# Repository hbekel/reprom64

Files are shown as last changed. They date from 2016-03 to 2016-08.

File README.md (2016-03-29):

#reprom64
*rom replacement board for the C64*

This is a rom adapter board for the C64 which replaces all rom chips
with a single 64kb 27C512 Eprom, offering space for four different
kernals, four charsets and two basic roms.

It can be assembled for any C64 mainboard as well as for the SX64 CPU
board.

Please refer to the [project
page](http://www.henning-bekel.de/reprom64) for detailed
documentation.

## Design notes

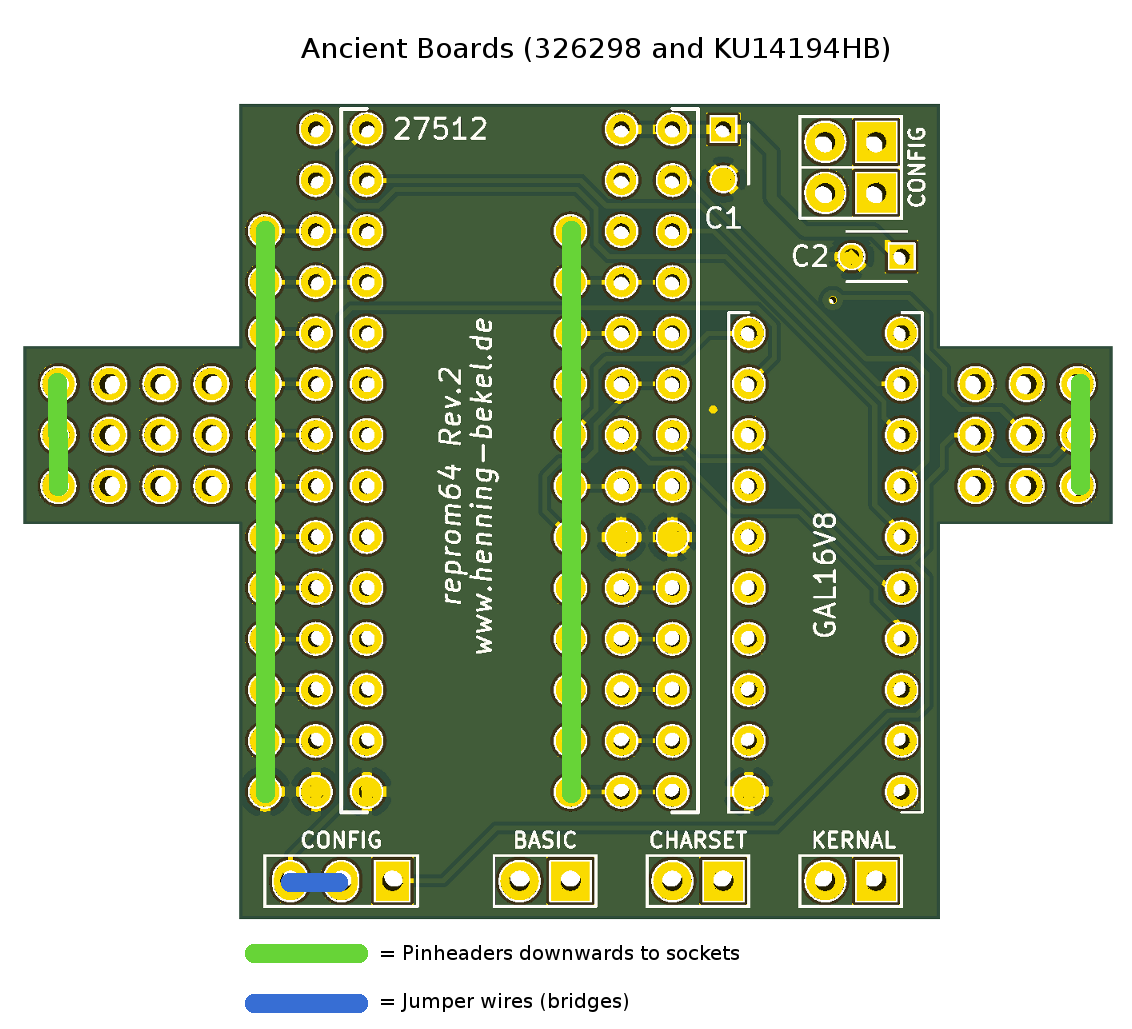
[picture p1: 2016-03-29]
doc/reprom-ancient-board.png

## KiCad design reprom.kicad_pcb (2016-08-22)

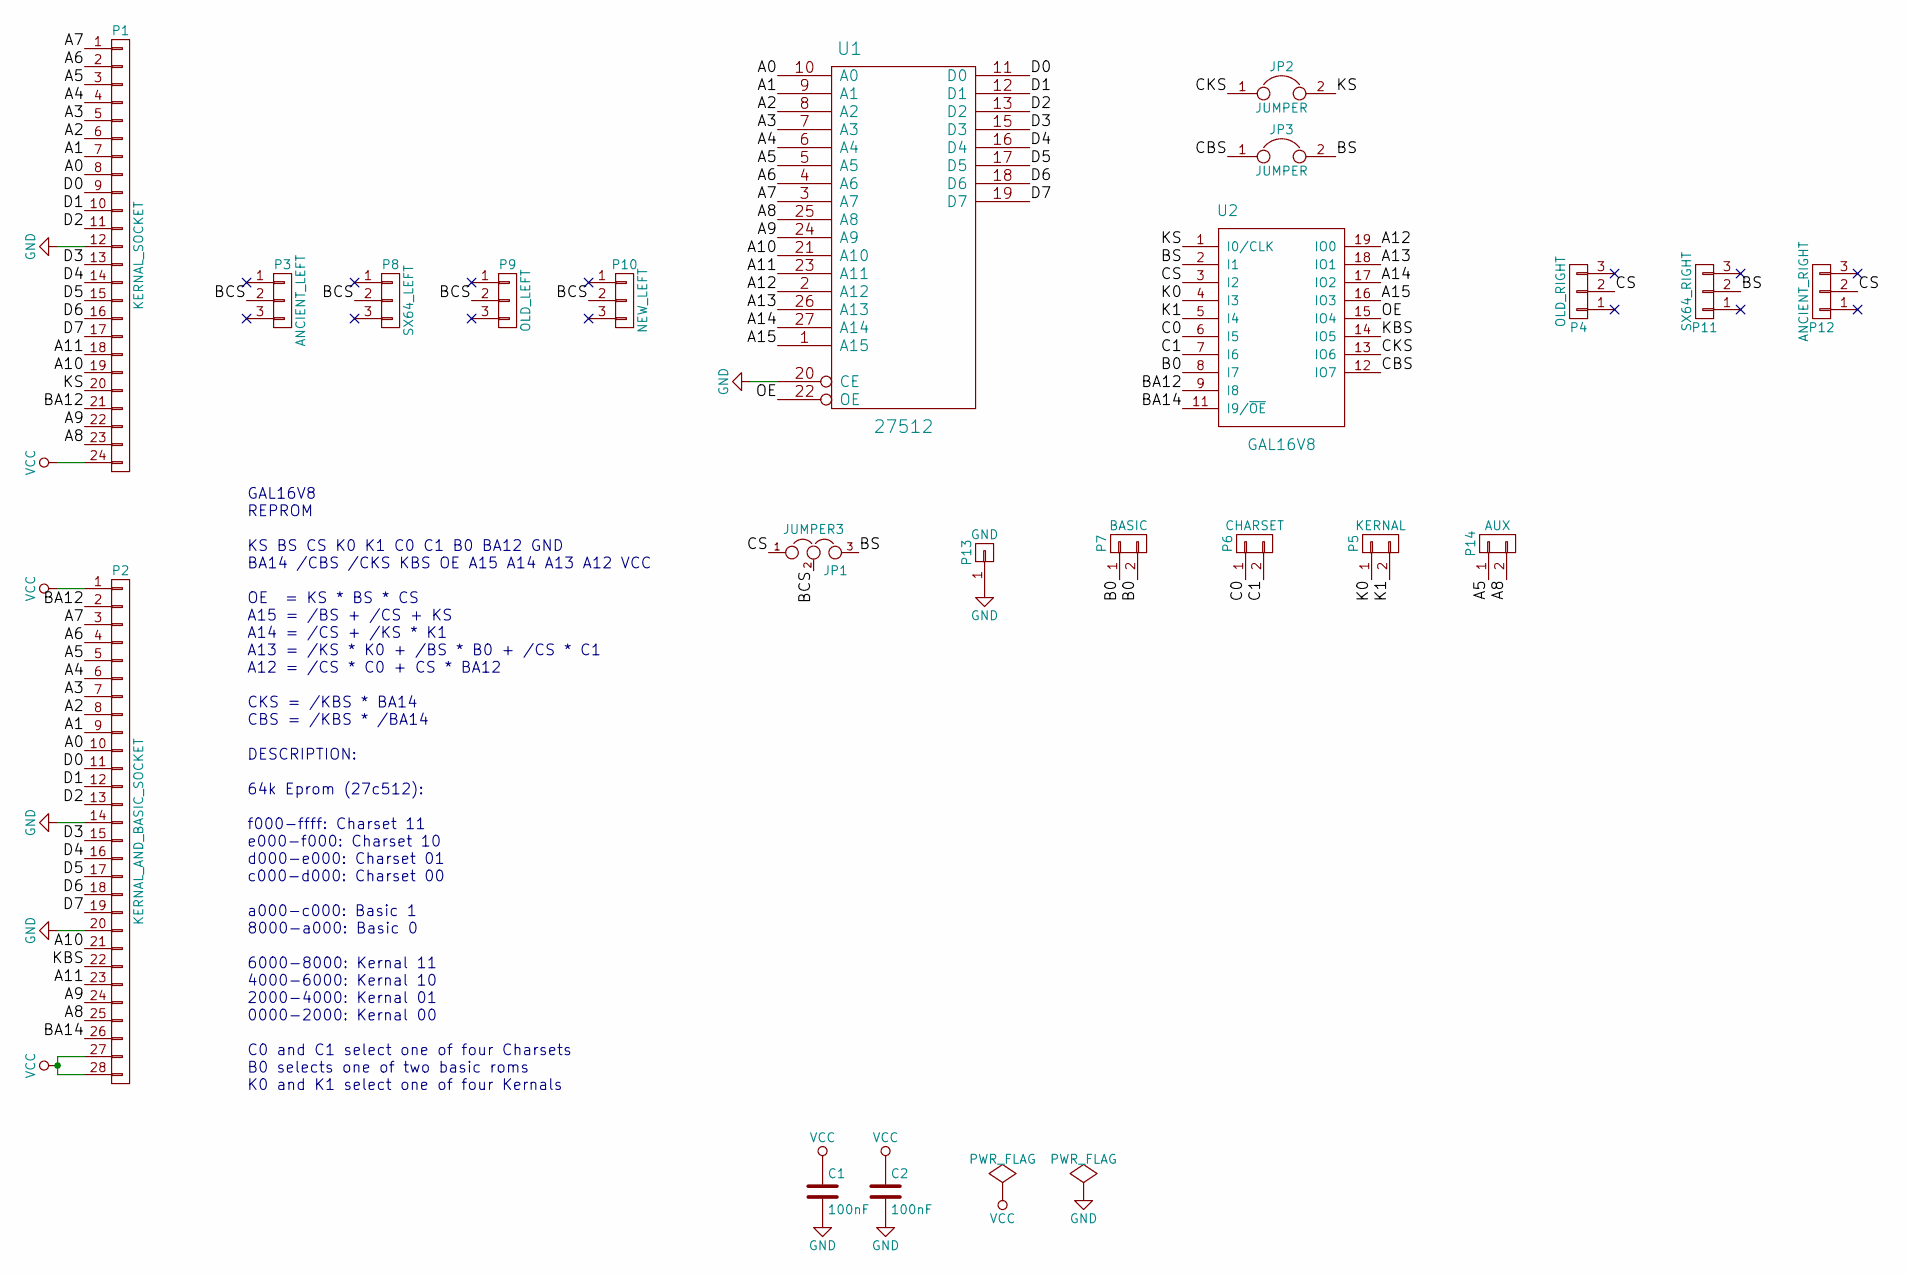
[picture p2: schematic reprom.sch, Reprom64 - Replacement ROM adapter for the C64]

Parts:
C1, C2: 100nF; C_Disc_D3_P2.5
JP1: JUMPER3; Pin_Header_Straight_1x03
JP2, JP3: JUMPER; Pin_Header_Straight_1x02
P1: KERNAL_SOCKET; DIP-24_W15.24mm
P2: KERNAL_AND_BASIC_SOCKET; DIP-28_W15.24mm
P3: ANCIENT_LEFT; Pin_Header_Straight_1x03
P4: OLD_RIGHT; Pin_Header_Straight_1x03
P5: KERNAL; Pin_Header_Straight_1x02
P6: CHARSET; Pin_Header_Straight_1x02
P7: BASIC; Pin_Header_Straight_1x02
P8: SX64_LEFT; Pin_Header_Straight_1x03
P9: OLD_LEFT; Pin_Header_Straight_1x03
P10: NEW_LEFT; Pin_Header_Straight_1x03
P11: SX64_RIGHT; Pin_Header_Straight_1x03
P12: ANCIENT_RIGHT; Pin_Header_Straight_1x03
P13: GND; Pin_Header_Straight_1x01
P14: AUX; Pin_Header_Straight_1x02
U1: 27512; DIP-28_W15.24mm
U2: GAL16V8; DIP-20_W7.62mm

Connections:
/A0: P1.8, P2.10, U1.10 (A0)
/A1: P1.7, P2.9, U1.9 (A1)
/A2: P1.6, P2.8, U1.8 (A2)
/A3: P1.5, P2.7, U1.7 (A3)
/A4: P1.4, P2.6, U1.6 (A4)
/A5: P1.3, P2.5, P14.1, U1.5 (A5)
/A6: P1.2, P2.4, U1.4 (A6)
/A7: P1.1, P2.3, U1.3 (A7)
/A8: P1.23, P2.25, P14.2, U1.25 (A8)
/A9: P1.22, P2.24, U1.24 (A9)
/A10: P1.19, P2.21, U1.21 (A10)
/A11: P1.18, P2.23, U1.23 (A11)
/A12: U1.2 (A12), U2.19 (IO0)
/A13: U1.26 (A13), U2.18 (IO1)
/A14: U1.27 (A14), U2.17 (IO2)
/A15: U1.1 (A15), U2.16 (IO3)
/B0: P7.1, P7.2, U2.8 (I7)
/BA12: P1.21, P2.2, U2.9 (I8)
/BA14: P2.26, U2.11 (I9/~OE)
/BCS: JP1.2, P3.2, P8.2, P9.2, P10.2
/BS: JP1.3, JP3.2, P11.2, U2.2 (I1)
/C0: P6.1, U2.6 (I5)
/C1: P6.2, U2.7 (I6)
/CBS: JP3.1, U2.12 (IO7)
/CKS: JP2.1, U2.13 (IO6)
/CS: JP1.1, P4.2, P12.2, U2.3 (I2)
/D0: P1.9, P2.11, U1.11 (D0)
/D1: P1.10, P2.12, U1.12 (D1)
/D2: P1.11, P2.13, U1.13 (D2)
/D3: P1.13, P2.15, U1.15 (D3)
/D4: P1.14, P2.16, U1.16 (D4)
/D5: P1.15, P2.17, U1.17 (D5)
/D6: P1.16, P2.18, U1.18 (D6)
/D7: P1.17, P2.19, U1.19 (D7)
/K0: P5.1, U2.4 (I3)
/K1: P5.2, U2.5 (I4)
/KBS: P2.22, U2.14 (IO5)
/KS: JP2.2, P1.20, U2.1 (I0/CLK)
/OE: U1.22 (OE), U2.15 (IO4)
GND: C1.2, C2.2, P1.12, P2.14, P2.20, P13.1, U1.14 (GND), U1.20 (CE), U2.10 (GND)
VCC: C1.1, C2.1, P1.24, P2.1, P2.27, P2.28, U1.28 (VCC), U2.20 (VCC)

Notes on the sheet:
GAL16V8 REPROM KS BS CS K0 K1 C0 C1 B0 BA12 GND BA14 /CBS /CKS KBS OE A15 A14 A13 A12 VCC OE = KS * BS * CS A15 = /BS + /CS + KS A14 = /CS + /KS * K1 A13 = /KS * K0 + /BS * B0 + /CS * C1 A12 = /CS * C0 + CS * BA12 CKS = /KBS * BA14 CBS = /KBS * /BA14 DESCRIPTION: 64k Eprom (27c512): f000-ffff: Char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

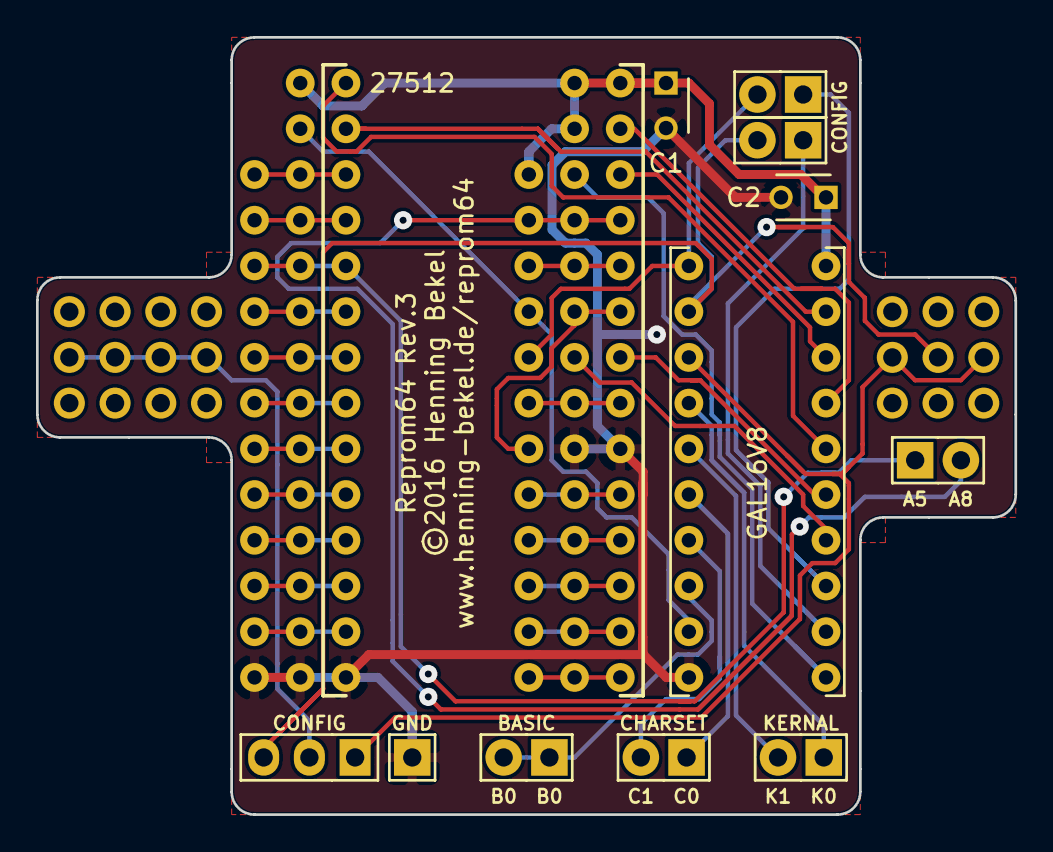
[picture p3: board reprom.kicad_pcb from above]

Board: 2 copper layers, 54.4 x 43.2 mm, 21 parts (0 on the bottom side), 41 nets.

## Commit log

2016-01-18 Hardware: Removed crappy autorouting, improved part placement
    [reprom.kicad_pcb, reprom.sch]
2016-01-18 Hardware: Some initial routing
    [reprom.dsn, reprom.kicad_pcb]
2016-01-19 Hardware: Improved routing, designed silkscreen, improved schematics
    [reprom.kicad_pcb, reprom.sch]
2016-01-19 Hardware: Improved routing
    [reprom.kicad_pcb]
2016-01-20 Hardware: Revision 1 (prototype), added gerber files
    [reprom.kicad_pcb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]
2016-03-07 Housekeeping: changed file modes for non-executable files
    [reprom.kicad_pcb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]
2016-03-16 Hardware: Added additional pin headers for wider rom layouts (KU/326298)
    [reprom.kicad_pcb, reprom.sch]
2016-03-16 Revert "Hardware: Added additional pin headers for wider rom layouts (KU/326298)"
    This reverts commit 2e8d7ef8814329ef0b47112793623fe7f19c62f6.
    [reprom.kicad_pcb, reprom.sch]
2016-03-17 Hardware: Added support for all board types
    This adds the pin headers required to use the adapter
    on ancient boards (396298 and KU14194HB) and on the
    SX64 CPU board (251102).
    [reprom.kicad_pcb, reprom.sch]
2016-03-22 Hardware: Improved silkscreen, added board rev info
    [reprom.kicad_pcb]
2016-03-22 Documentation: Added gimp image showing different assembly options
2016-03-29 Documentation: Added renderings of different assembly options
2016-03-29 Housekeeping: Removed gerber files, fixed file modes, Version bumped
    Since different board houses have different requirements for gerber files,
    it makes no sense to put them into the repository.
    [reprom.kicad_pcb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]
2016-05-29 Hardware: Added GND connector, improved layout, silkscreen and 3d view
    [reprom.kicad_pcb, reprom.sch]
2016-05-30 Hardware: Added Revision 2 gerber files for production
    [reprom.kicad_pcb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]
2016-05-30 Hardware: Removed gerber files for development
    [reprom.kicad_pcb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]
2016-05-31 Hardware: Fixed header placement, added Revision 2 gerber files again
    Fixed pin header placement (now on 2.54mm grid to allow single connector).
    [reprom.kicad_pcb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]
2016-06-01 Version 1.2
    Only minor changes in this version:
    * Added pin header for GND
    * Aligned pin headers in 2.54mm Spacing (0.1")
    [reprom.kicad_pcb, reprom.sch]
2016-07-28 Hardware: Added additional pin header for A5 and A8, rounded corners
    [reprom.kicad_pcb, reprom.sch]
2016-08-17 Hardware: Moved A5 and A8 header to a more convenient location
    [reprom.kicad_pcb]
2016-08-18 Hardware: Improved silkscreen, routing
    [reprom.kicad_pcb]
2016-08-22 Hardware: Reversed order of A5 and A8
    [reprom.kicad_pcb]
2016-08-22 Version 1.3 Revision 3, added gerber files
    [reprom.kicad_pcb, reprom.sch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]

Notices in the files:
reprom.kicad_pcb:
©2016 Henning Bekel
